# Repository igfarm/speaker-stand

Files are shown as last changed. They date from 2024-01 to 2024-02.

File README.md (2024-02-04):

# Tripod Speaker Stand

This is an OpenSCAD file for creating a tripod speaker stand using PVC pipe and 3D printed components.

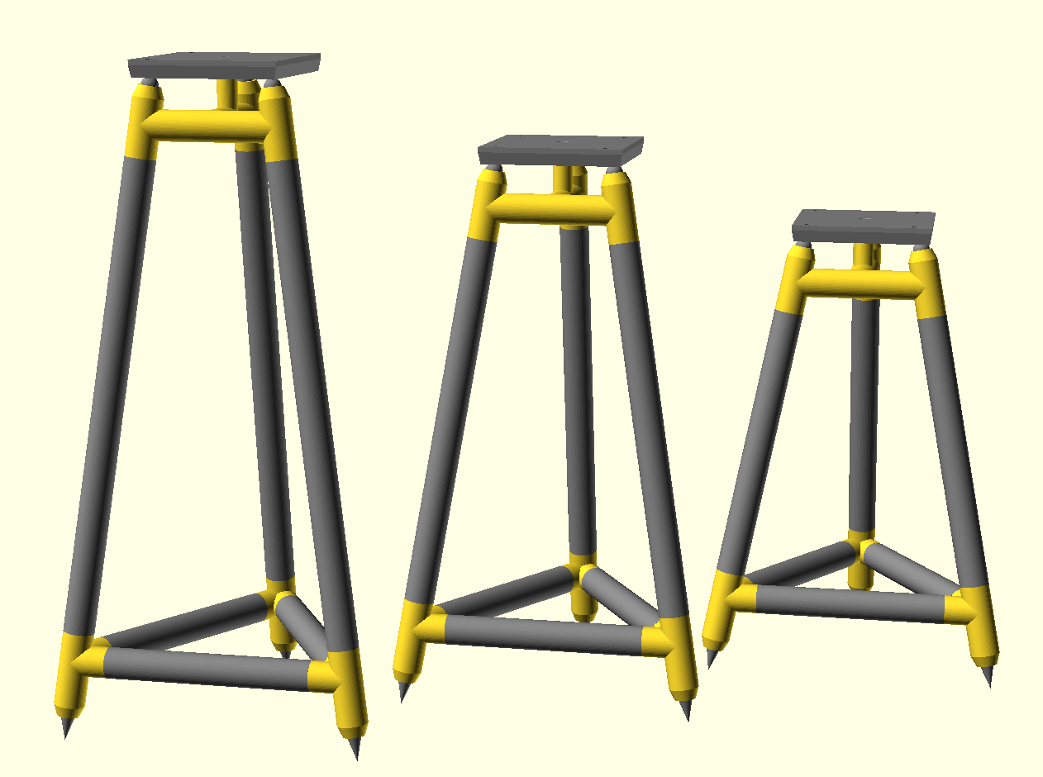
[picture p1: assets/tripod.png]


The top plate for the speaker is attached with a single 1/4"-20 screw. The bottom of the stand features threaded spikes.

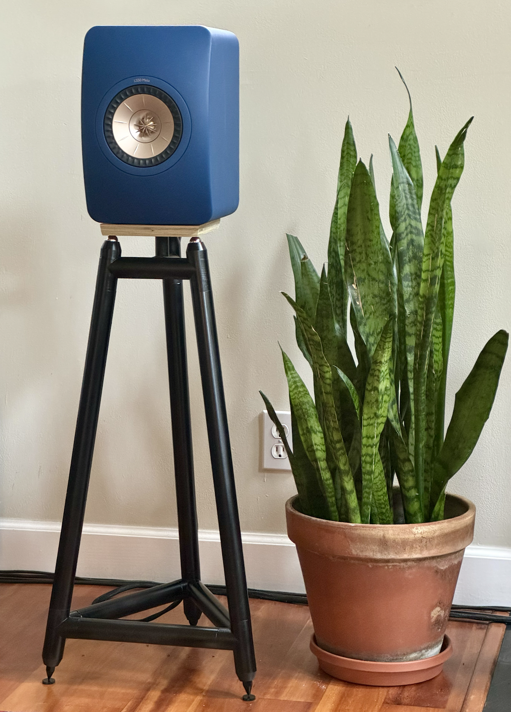
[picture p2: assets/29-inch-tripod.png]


## OpenSCAD File

The provided OpenSCAD file allows customization of various stand dimensions and features:

- `default_height`: Total height of the stand, including spikes and top plate.
- `default_width`: Distance between two legs.
- `plate_width`: Width of top plate.
- `plate_height`: Height of top plate.
- `leg_odiam`: Outside diamater of leg PVC pipe.
- `leg_idiam`: Inside diamater of leg PVC pipe.
- `show_part`: Render the part to be printed. Values are `top`, `bottom`, `plate`, `all`, and `hero`.

Adjust these and other parameters to tailor the stand to your requirements.

Additional display options include toggling the visibility of the spikes, top plate, and inner diameter PVC pipe.

**Note:** The BOSL2 library is required for thread generation. Installation details are available at https://github.com/BelfrySCAD/BOSL2

## Generating 3D Printed Parts using SCAD File

I would recommend the following process:

1. Get a sample PVC pipe you will be using and measure the inner and outer diameter of the pipe
1. Check the screw and spike threads types
1. Decide height of the stand
1. Adjust model with all information above
1. Print the test article
1. Print other parts

To create printable 3D parts using the SCAD file:

- `default_show`: part to show, values are "all", "hi", "low", "plate", and "test"

These parts are suitable for printing on a Prusa Mini printer with a 7"x7"x7" bed using the
standard geometry.

## Construction Notes

See the wiki at https://github.com/igfarm/speaker-stand/wiki

## Materials

This is a sample list using vendors in the US.

- 1" schedule 40 PVC pipe for legs and trusses
- Speaker spikes with M6 thread ([Amazon Link](https://www.amazon.com/gp/product/B09K3H8FD9/)) ([AliExpress Link](hhttps://www.aliexpress.us/item/3256804460518547.html))

- 3/4" Steel balls ([Amazon Link](https://www.amazon.com/gp/product/B07D9SSKN8/))
- 1/4"-20 bolt to connect top plate to stand
- Epoxy to glue connectors to tubes
- 3D printed parts
- Sand to fill the legs
- Paint

Please print the test article to make sure the PVC pipe pipe and threads fit. Adjust the source code as needed.

## 3D Printed Parts

I created some examples renders based on standard height and PVC pipe from Home Depot.

- [21" Height](./examples/1-inch-charlotte-pipe/21-inch/)
- [25" Height](./examples/1-inch-charlotte-pipe/25-inch/)
- [29" Height](./examples/1-inch-charlotte-pipe/29-inch/)

### Test Article

This part is used to verify your model settings are correct to fit the pipe and other parts you use. Recommeded to print this before the other parts.

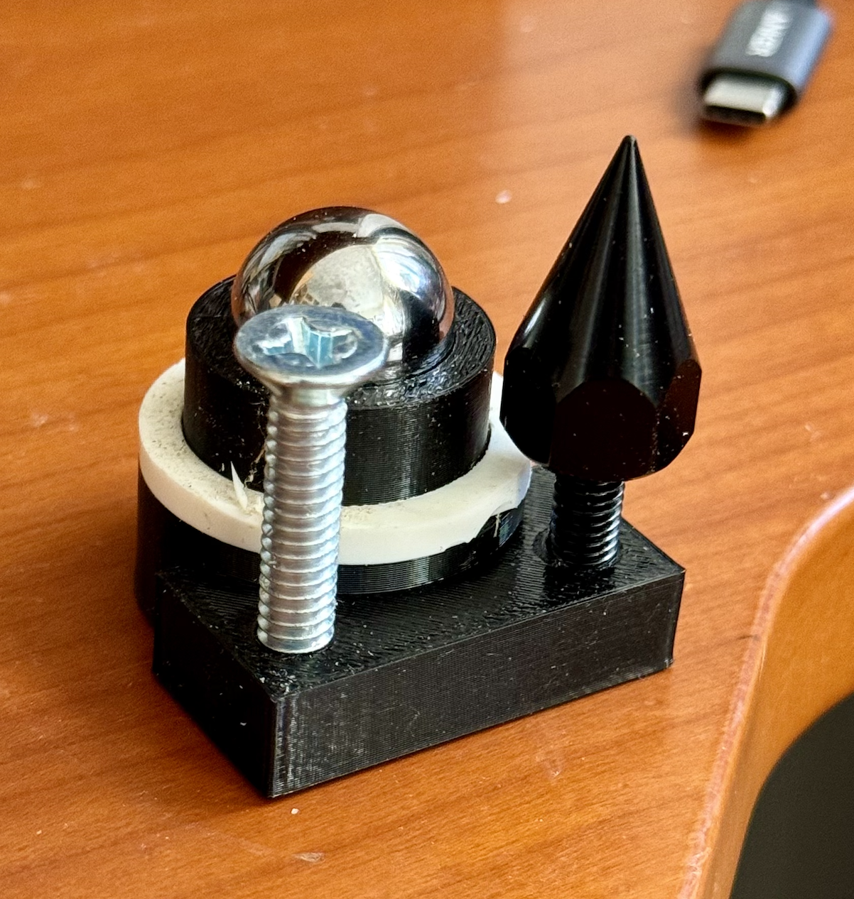
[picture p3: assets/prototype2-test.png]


### Top Connector

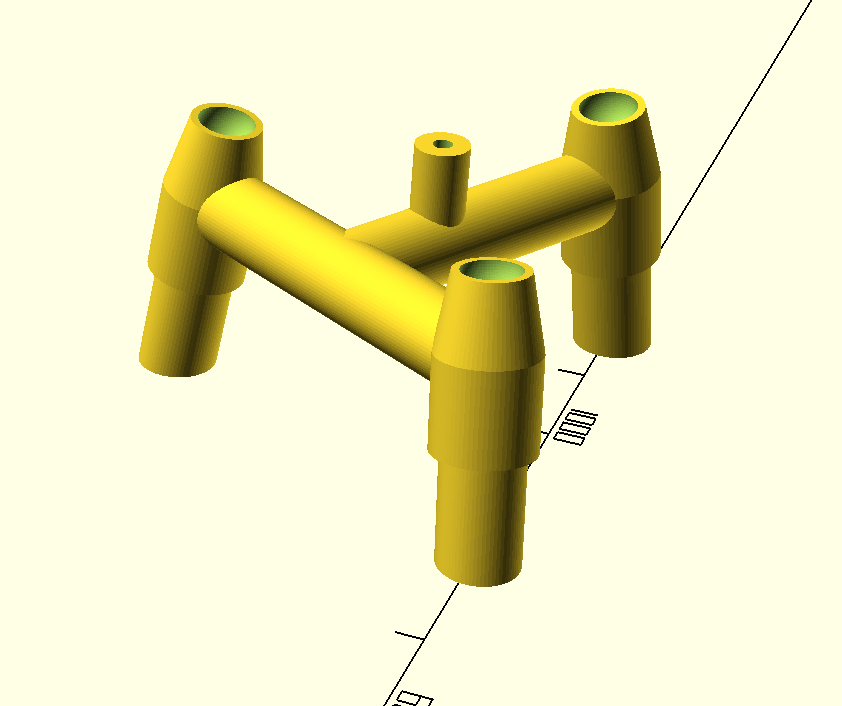
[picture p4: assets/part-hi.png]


### Bottom Connector

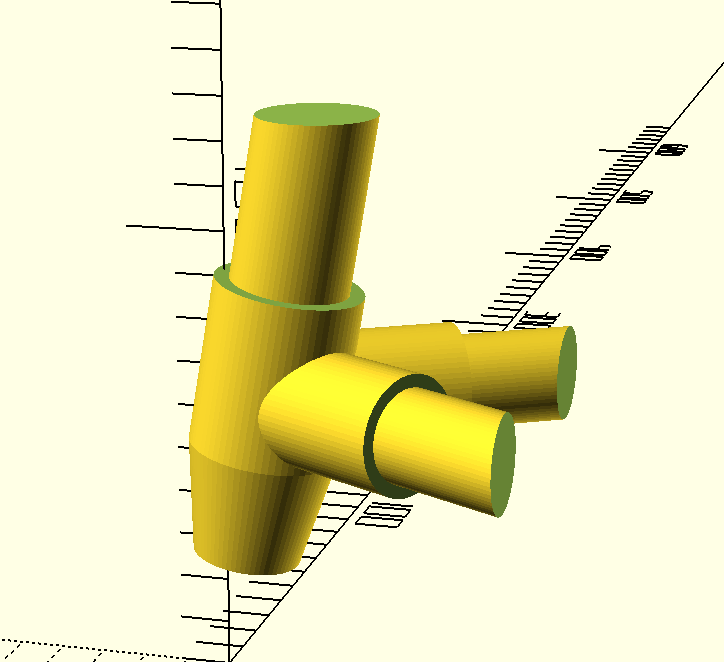
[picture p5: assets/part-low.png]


### Plate (optional)

This is probably done better with MDF or plywoood.

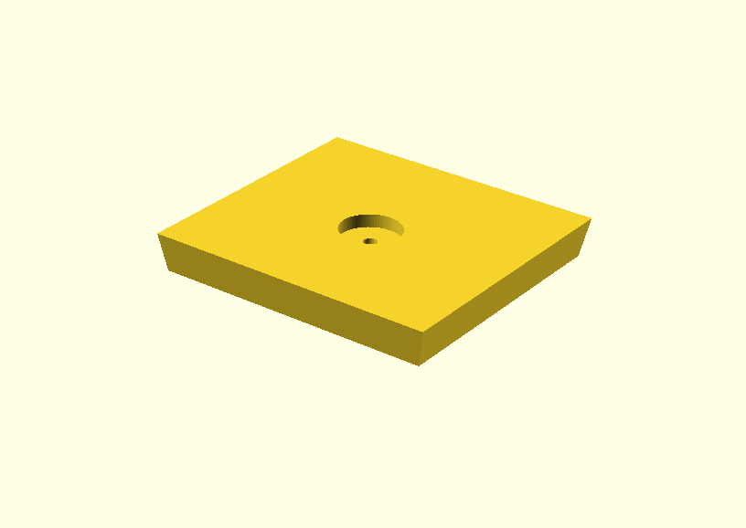
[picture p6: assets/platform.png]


## Development

### Third Prototype

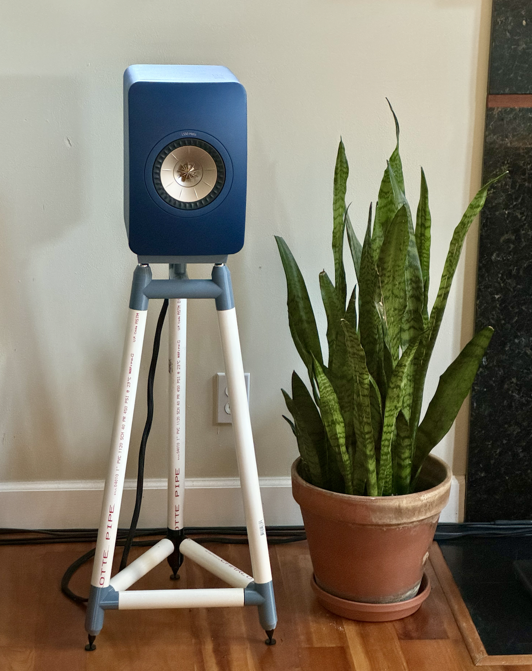
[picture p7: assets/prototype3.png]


### Second Prototype

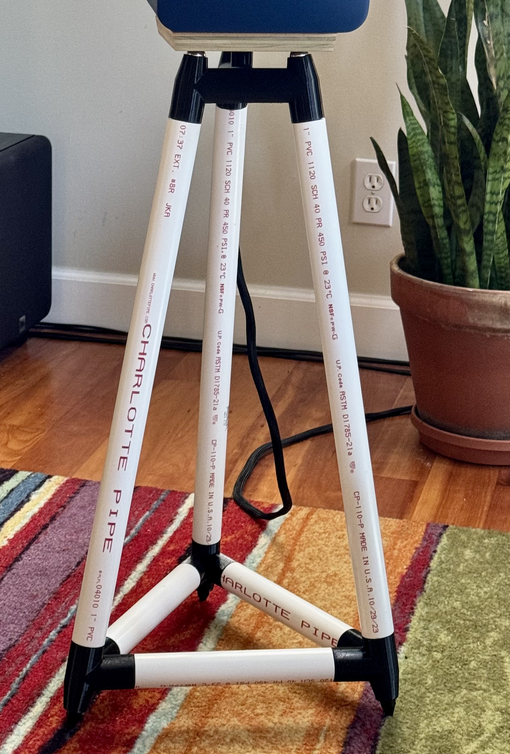
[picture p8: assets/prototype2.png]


Starting to look like the real thing.

- Need to fine tune the gemoetry.
- Print orientation is importat to get proper fitting parts.
- Added a print test article.



### First Prototype

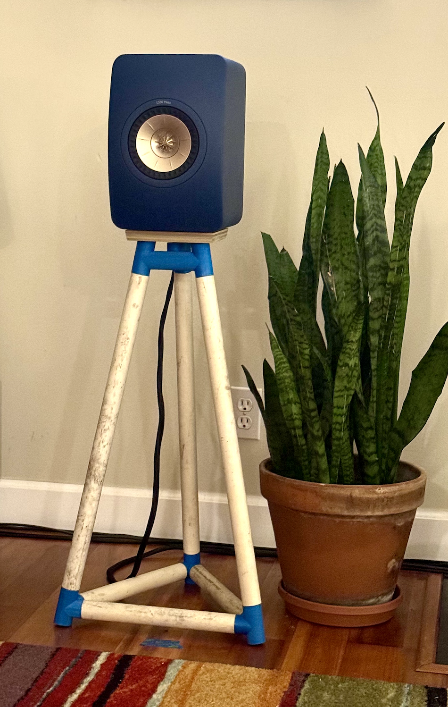
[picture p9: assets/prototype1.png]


This proof of concept was made using old PVC pipes found in the garage.

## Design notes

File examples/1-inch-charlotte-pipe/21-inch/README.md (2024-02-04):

# 21" Speaker Stand

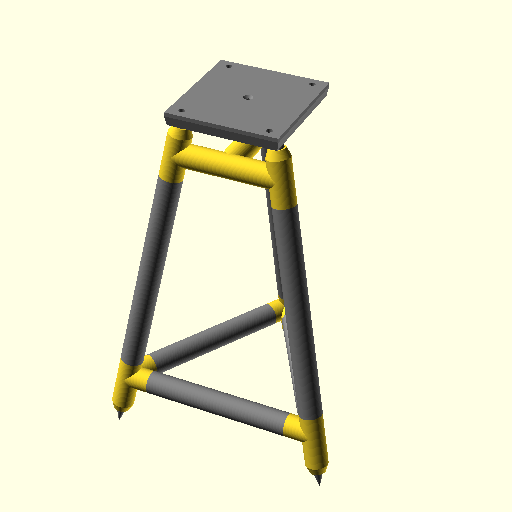
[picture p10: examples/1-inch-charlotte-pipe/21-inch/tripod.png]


## STL Files
-   [Plate](./tripod-plate.stl)
-   [Top Brace](./tripod-hi.stl)
-   [Low Brace](./tripod-low.stl)
-   [All Parts](./tripod.stl)
-   [Test Print](./tripod-test.stl)

## Tube Lengths (in mm)
```
 "leg tube length", 316.501
 "low truss tube length", 218.216
```

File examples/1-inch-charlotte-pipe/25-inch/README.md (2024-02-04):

# 25" Speaker Stand

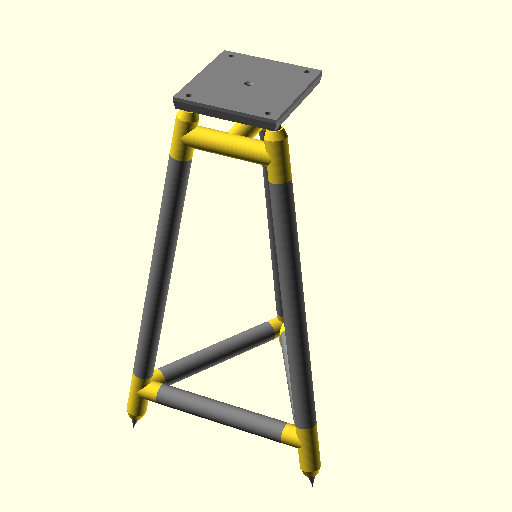
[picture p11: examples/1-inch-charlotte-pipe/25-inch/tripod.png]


## STL Files
-   [Plate](./tripod-plate.stl)
-   [Top Brace](./tripod-hi.stl)
-   [Low Brace](./tripod-low.stl)
-   [All Parts](./tripod.stl)
-   [Test Print](./tripod-test.stl)

## Tube Lengths (in mm)
```
 "leg tube length", 417.09
 "low truss tube length", 223.867
```

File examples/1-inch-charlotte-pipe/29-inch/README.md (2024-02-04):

# 29" Speaker Stand

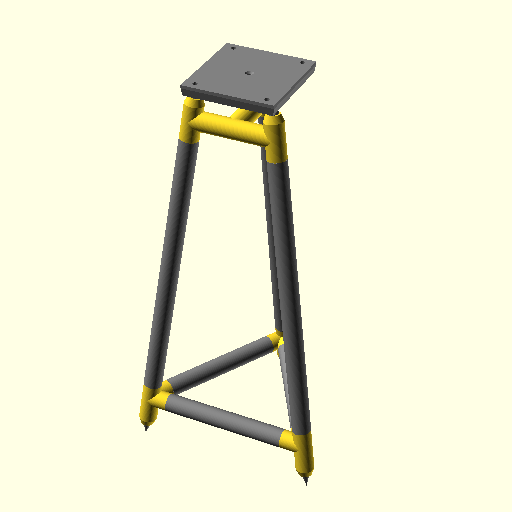
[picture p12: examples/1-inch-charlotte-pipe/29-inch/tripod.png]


## STL Files
-   [Plate](./tripod-plate.stl)
-   [Top Brace](./tripod-hi.stl)
-   [Low Brace](./tripod-low.stl)
-   [All Parts](./tripod.stl)
-   [Test Print](./tripod-test.stl)

## Tube Lengths (in mm)
```
 "leg tube length", 517.843
 "low truss tube length", 227.918
```

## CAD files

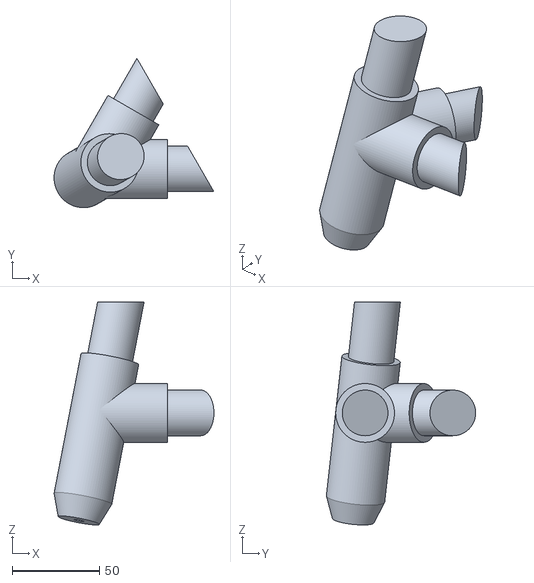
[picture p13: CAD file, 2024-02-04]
examples/1-inch-charlotte-pipe/21-inch/tripod-low.stl
91.5 x 85.5 x 127.7

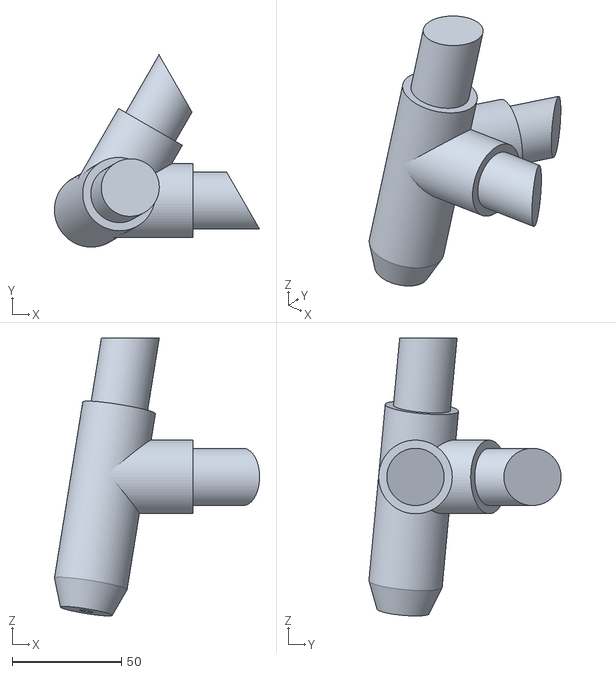
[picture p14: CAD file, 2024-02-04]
examples/1-inch-charlotte-pipe/25-inch/tripod-low.stl
93.8 x 87.9 x 127.1

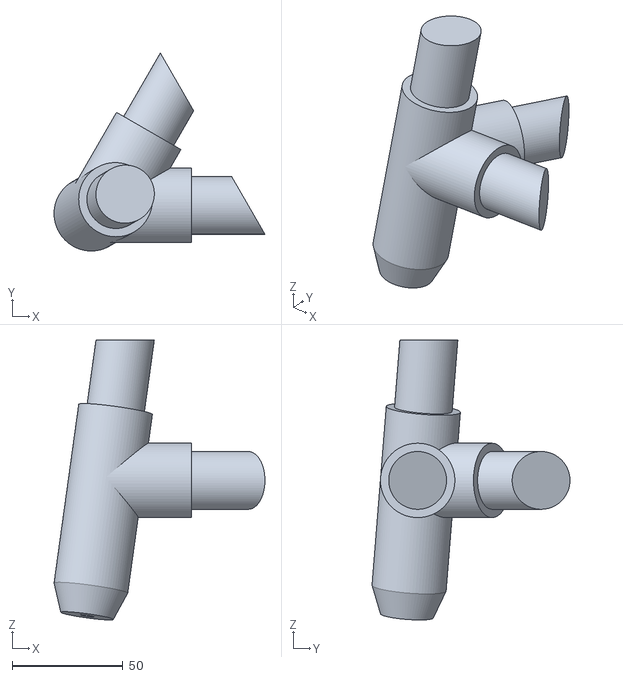
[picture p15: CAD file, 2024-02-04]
examples/1-inch-charlotte-pipe/29-inch/tripod-low.stl
95.4 x 89.6 x 126.6

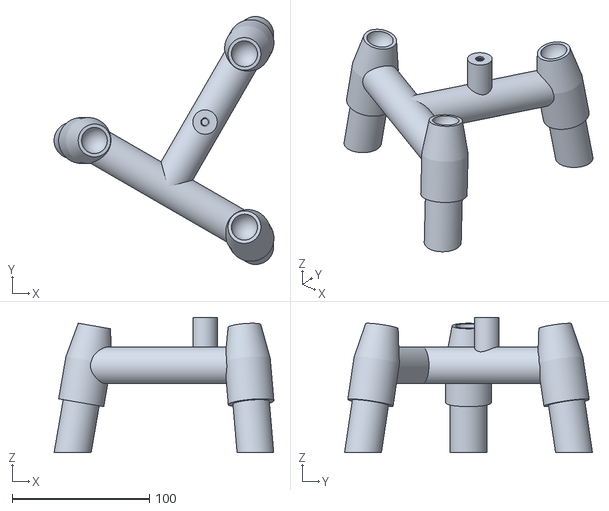
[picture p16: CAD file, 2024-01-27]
examples/28-inch/tripod-hi.stl
160.2 x 180.8 x 98.4

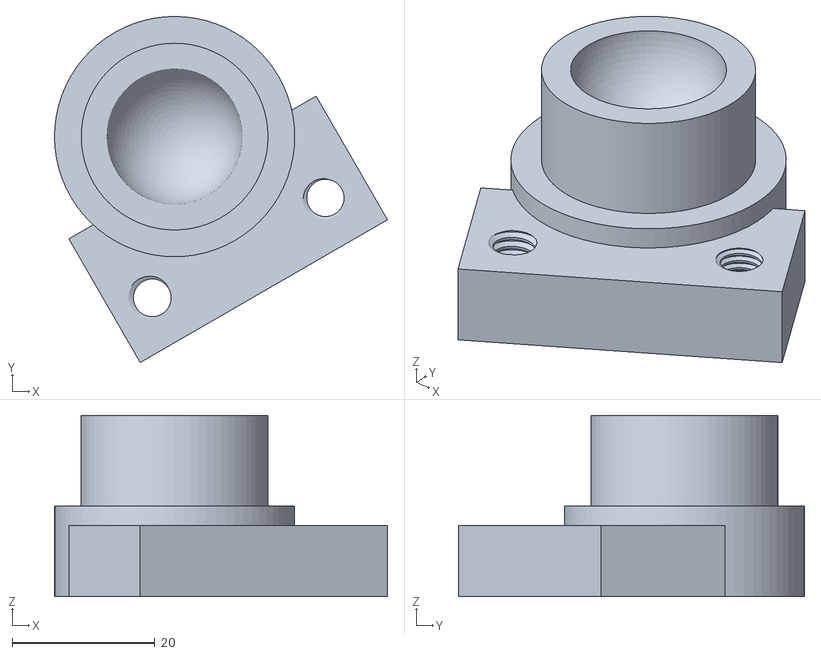
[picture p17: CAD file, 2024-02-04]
examples/1-inch-charlotte-pipe/21-inch/tripod-test.stl
46.6 x 48.5 x 25.4

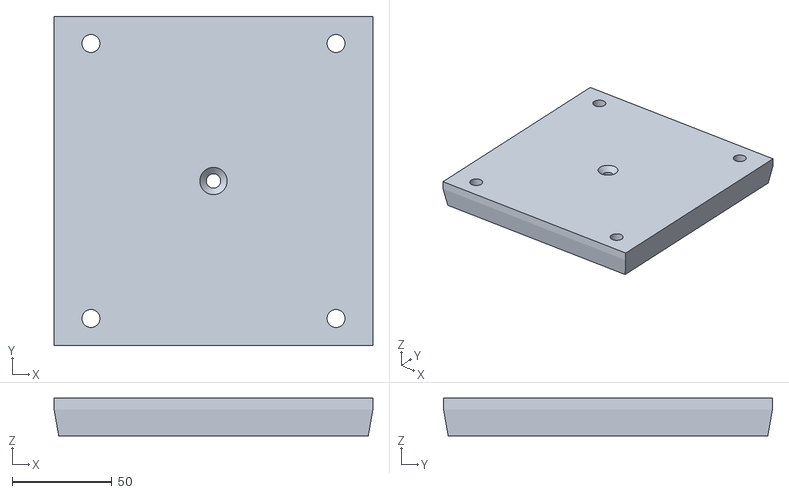
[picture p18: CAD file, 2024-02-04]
examples/1-inch-charlotte-pipe/25-inch/tripod-plate.stl
160.0 x 165.1 x 19.1

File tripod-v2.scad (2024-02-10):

/*
This file is part of the speaker-stand project.

The speaker-stand project is free software: you can redistribute it 
and/or modify it under  the terms of the GNU General Public License 
as published by the Free Software Foundation, either version 3 of 
the License, or (at your option) any later version.

The speaker-stand project is distributed in the hope that it will be 
useful, but WITHOUT ANY WARRANTY; without even the implied warranty 
of MERCHANTABILITY or FITNESS FOR A PARTICULAR PURPOSE. See the GNU 
General Public License for more details.

You should have received a copy of the GNU General Public License along 
with the project. If not, see <https://www.gnu.org/licenses/>.
*/

// ../formatter/scadformat/scadformat ./tripod.scad

$fn = 72;
include <BOSL2/std.scad>
include <BOSL2/threading.scad>
include <BOSL2/screws.scad>

default_height = 29 * INCH;
default_width = 14 * INCH;
default_show = "all";


module _stand(height, width, show) {

  base_width = width;
  stand_height = height;

  plate_width = 6.5 * INCH;
  plate_depth = 7 * INCH;
  plate_height = 0.75 * INCH;
  plate_angle = 10;

  // https://pvcfittingstore.com/pages/pvc-pipe-sizes-and-dimensions
  leg_odiam = 1.325 * INCH;// Set up for 1" schedule 40 PVC
  leg_idiam = 1.03 * INCH;

  truss_odiam = leg_odiam;
  truss_idiam = leg_idiam;

  top_diameter = plate_width / sqrt(3) * 2 - leg_odiam ;
  // top_diameter = 5.3 * INCH;

  taper_length = INCH / 2;

  top_margin = INCH * 2.0;
  bottom_margin = INCH * 3.5;
  top_rad = top_diameter / 2;

  // Spike
  spike_diam = 16;
  spike_length = 28;
  spike_thread = 6;
  spike_thread_pitch = 1;
  spike_thread_length = 13;

  // Kef LM50
  speaker_width = 200;
  speaker_depth = 260;
  speaker_height = 10;// 302;

  speaker_hole_depth = 138;
  speaker_hole_width = 123;
  speaker_hole_screw = "M8";
  speaker_hole_screw_head = "socket";

  // Plate Screw
  plate_screw_diam = 1 / 4 * INCH;
  plate_screw_pitch = 1 / 20 * INCH;

  // Steel ball
  sphere_diameter = 0.5 * INCH;

  // Flags to show different things
  // Flags to show different things
  show_part = show != "all";
  part = show;// Values are hi, low, plate

  show_spike = true;
  show_top = true;
  show_inner = false;
  show_speaker = true;

  top_angle = 60;
  bottom_angle = 60;

  truss_orad = truss_odiam / 2;
  truss_irad = truss_idiam / 2;

  leg_orad = leg_odiam / 2;
  leg_irad = leg_idiam / 2;

  alt_stand_height = stand_height - plate_height;
  top_radius = top_diameter / 2;

  plate_offset = 0; // -1 / 4 * top_radius;

  base_diamater = base_width / sqrt(3) * 2;
  base_radius = base_diamater / 2;

  // Oversize thread diamater adjusment.
  // This value works using Prusa Mini+ using PLA
  thread_adjusment = 0.3;

  module my_thread(diameter, pitch, length) {
    if (show_part) {
      translate([0, 0, length / 2])
        threaded_rod(d = diameter + thread_adjusment, height = length, pitch = pitch, $fa = 0.5, $fs = 0.5, internal = true);
    } else {
      translate([0, 0, -1])
        cylinder(length + 2, diameter / 2, diameter / 2);
    }
  }

  // Transpose of matrix A (swap rows and columns)
  function transpose(A) = [ for(j = [0:len(A[0]) - 1])
    [ for(i = [0:len(A) - 1])A[i][j]]
  ];

  //  Cylinder of radius r from P to Q
  module cylinder_between_points(P, Q, r, taper = 0, irad = 0, add_spike = false, use_cube = false) {
    v = Q - P;// vector from P to Q
    L = norm(v);// height of the cylnder = dist(P, Q)
    c = v / L;// unit vector: direction from P to Q
    is_c_vertical = (1 - abs(c * [0, 0, 1]) < 1e-6);//is c parallel to z axis?
    u = is_c_vertical ? [1, 0, 0] : cross([0, 0, 1], c);// normal to c and Z axis
    a = u / norm(u);// unit vector normal to c and the Z axis
    b = cross(c, a);// unit vector normal to a and b
    // [a, b, c] is an orthonormal basis, i.e. the rotation matrix; P is the translation
    MT = [a, b, c, P];// the transformation matrix
    M = transpose(MT);// OpenSCAD wants vectors in columns, so we need to transpose
    multmatrix(M) {
      difference() {
        union() {
          length = L - taper;
          difference() {
            if (use_cube) {
              th = r * 2.5;
              tw = r;
              translate([-tw/2, -th/2, 0]) 
                cube([tw, th, length]);
            }
            else
              cylinder(h = length, r = r);

            if (irad > 0) {
              tube_length = length - truss_idiam * 2 - INCH;
              translate([0, 0, (length - tube_length) / 2]) {
                difference() {
                  cylinder(h = tube_length, r = r + 0.1);
                  cylinder(h = tube_length, r = irad);
                }
              }
            }
          }

          if (taper > 0) {
            translate([0, 0, L - taper]) {
              cylinder(taper, r, spike_diam / 2 * 1.5);
            }
          }

          if (add_spike && show_spike)
          color("grey")
            translate([0, 0, L])
              cylinder(spike_length, spike_diam / 2, 0);
        }

        if (add_spike) {
          sl = spike_thread_length * 1.5;
          translate([0, 0, L - sl]) {
            my_thread(diameter = spike_thread, pitch = spike_thread_pitch, length = sl);
          }
        }
      }
    }
  }

  // Calculate all interesting points on the design
  bottom_z = bottom_margin;
  bottom_rad = default_width / 2;
  top_z = height - top_margin - plate_height - sphere_diameter / 2;
  cone_slope = (top_rad - bottom_rad) / (top_z - bottom_z);
  cone_height = -bottom_rad / cone_slope + bottom_z;

  function cone_rad_at(height) = cone_slope * (height - bottom_z) + bottom_rad;

  // get coordinate of three points around circle r at height z
  function tcords(r, z, angle = 60, offset = 0) = [
    [r + offset, 0, z], 
    [-r * cos(angle) + offset, r * sin(angle), z], 
    [-r * cos(angle) + offset, -r * sin(angle), z]
  ];

  // get coordinate of three points around height z
  function zcords(z, angle = 60, offset = 0) = tcords(cone_rad_at(z), z, angle, offset);

  t0 = zcords(bottom_z, bottom_angle);
  p0 = t0[0];
  p1 = t0[1];
  p2 = t0[2];

  t1 = zcords(spike_length);
  p0a = t1[0];
  p1a = t1[1];
  p2a = t1[2];

  t2 = zcords(top_z);
  p3 = t2[0];
  p4 = t2[1];
  p5 = t2[2];

  t3 = zcords(top_z + top_margin, top_angle);
  p3a = t3[0];
  p4a = t3[1];
  p5a = t3[2];

  p6 = (p5 + p4) / 2;
  p7 = p3 + [-(p3[0] - p6[0]) / 2, 0, 0];
  p8 = p7 + [0, 0, top_margin + sphere_diameter / 2 - INCH / 8];

  // Put speheres in the intersection points to fill in the gaps
  if (false){
    for(p = [p0, p1, p2, p3, p4, p5]) {
    translate(p) {
      sphere(r = leg_orad);
    }
  }
}

  // Draw the connecting tubes
  union() {
    difference() {
      union() {
        cylinder_between_points(p0, p1, truss_orad, irad = truss_irad);
        cylinder_between_points(p1, p2, truss_orad, irad = truss_irad);
        cylinder_between_points(p2, p0, truss_orad, irad = truss_irad);

        cylinder_between_points(p0, p0a, leg_orad, taper_length, add_spike = true);
        cylinder_between_points(p1, p1a, leg_orad, taper_length, add_spike = true);
        cylinder_between_points(p2, p2a, leg_orad, taper_length, add_spike = true);

        cylinder_between_points(p0, p3, leg_orad, irad = leg_irad);
        cylinder_between_points(p1, p4, leg_orad, irad = leg_irad);
        cylinder_between_points(p2, p5, leg_orad, irad = leg_irad);

        cylinder_between_points(p4, p5, truss_orad, use_cube = true);
        cylinder_between_points(p3, p6, truss_orad, use_cube = true);

        cylinder_between_points(p3, p3a, leg_orad, taper_length);
        cylinder_between_points(p4, p4a, leg_orad, taper_length);
        cylinder_between_points(p5, p5a, leg_orad, taper_length);

        cylinder_between_points(p7, p8, truss_orad/2);
      }

      // Top screw
      translate(p8) {
        rotate([180, 0, 0]) {
          my_thread(diameter = plate_screw_diam, pitch = plate_screw_pitch, length = INCH);
        }
      }

      // Make a nest for the spheres
      for(p = [p3a, p4a, p5a]) {
        translate(p) {
          color("grey")
            sphere(d = sphere_diameter);
        }
      }
    }
  }

  // Add top spheres and spikes
  if (show_spike) {
    for(p = [p3a, p4a, p5a]) {
      translate(p) {
        color("grey")
          sphere(d = sphere_diameter);
      }
    }
    if (false) for(p = [p0a, p1a, p2a]) {
      translate(p) {
        color("grey")
          translate([0, 0, -spike_length])
            cylinder(spike_length, 0, spike_diam / 2);
      }
    }
  }

  if ((show_top && !show_part) || (show_part && part == "plate")) {
    color("grey") {
      difference() {
        translate([p7[0], 0, alt_stand_height + plate_height / 2])
          rotate([0, 0, 180])
            translate([0, 0, 0])
              difference() {
                cube([plate_depth, plate_width, plate_height], center = true);
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

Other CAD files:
examples/1-inch-charlotte-pipe/29-inch/tripod-test.stl
examples/1-inch-charlotte-pipe/21-inch/tripod-plate.stl
examples/1-inch-charlotte-pipe/25-inch/tripod-test.stl
examples/1-inch-charlotte-pipe/29-inch/tripod-plate.stl
tripod.scad

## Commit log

2024-01-26 add examples and clean up unused vars
    [tripod-hi.stl, tripod-low.stl]
2024-01-26 fix file extension
    [tripod.stl]
2024-01-27 move to BOSL2 library threads
    [tripod-hi.stl, tripod-low.stl, tripod.scad]
2024-01-27 fix position top support so it lands between back and fron legs
    [tripod.scad]
2024-01-27 fix top placement
    [tripod-hi.stl, tripod.scad, tripod.stl]
2024-01-27 run formatter and updte image
    [tripod.scad]
2024-01-28 add generated examples
    [tripod-low.stl, tripod.stl]
2024-01-28 fix plate alignment
    [tripod.scad]
2024-01-28 fix spike thread
    [tripod.scad]
2024-01-29 fix sleves
    [tripod.scad]
2024-01-30 fix top plate
    [tripod.scad]
2024-01-30 fix show
    [tripod.scad]
2024-01-31 update comments
    [tripod.scad]
2024-01-31 fix plate offset
    [tripod.scad]
2024-01-31 make plate post tighter
    [tripod.scad]
2024-01-31 fix sphere indents
    [tripod.scad]
2024-02-01 fix platform holes
    [tripod.scad]
2024-02-04 add examples
    [tripod-low.stl, tripod-plate.stl, tripod-test.stl]
2024-02-04 move files
    [tripod-low.stl, tripod-plate.stl, tripod-test.stl]
